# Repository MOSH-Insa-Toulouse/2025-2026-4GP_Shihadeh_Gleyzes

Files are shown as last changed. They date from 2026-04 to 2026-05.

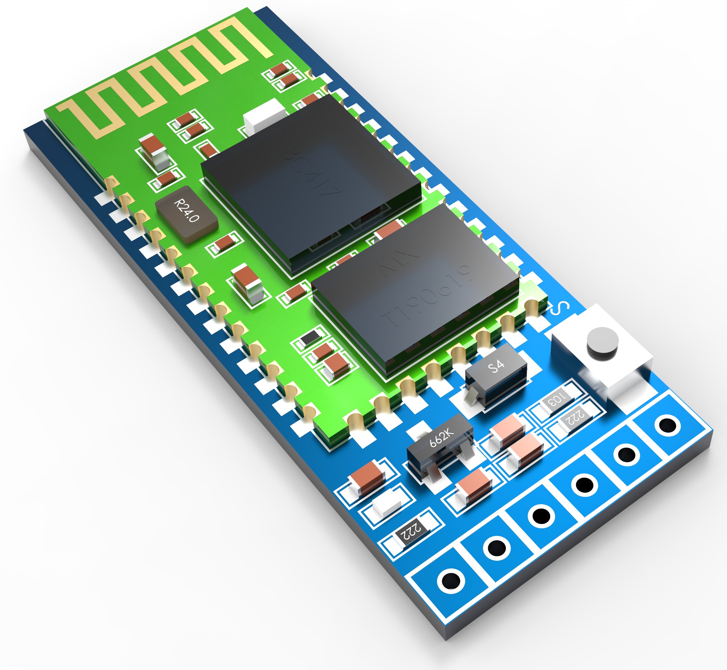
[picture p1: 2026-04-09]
Kicad/modules/module-bluetooth-hc05-1.snapshot.4/HC05_render.jpg

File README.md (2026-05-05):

#  Projet : Du capteur au banc de test - Jauge de contrainte en graphite

L'objectif principal de ce projet est d'évaluer une technologie "low-tech" : un capteur de déformation (jauge de contrainte) fabriqué à partir de graphite. Pour cela, nous avons conçu de A à Z une chaîne de mesure complète, allant de la physique du capteur jusqu'à l'application smartphone, en passant par le conditionnement électronique et la création d'un banc de test automatisé.

##  Équipe Projet
* **[Jules Gleyzes]**  **[Samy Shihadeh]**
* Année : 2025-2026

---

##  Sommaire des livrables
1. [Le Capteur en Graphite](#1-le-capteur-en-graphite-low-tech)
2. [Électronique Analogique et Simulation (LTspice)](#2-électronique-analogique-et-simulation-ltspice)
3. [Le Shield PCB (KiCad)](#3-le-shield-pcb-kicad)
4. [Le Code Arduino](#4-programmation-arduino)
5. [L'Application Android](#5-application-android)
6. [Le Banc de Test](#6-le-banc-de-test)
7. [La Datasheet Finale](#7-datasheet-du-capteur)
8. [Conclusion](#8-conclusion)

---

## 1. Le Capteur en Graphite (Low-Tech)
Notre jauge de contrainte a été fabriquée selon une approche "low-tech", en crayonnant simplement une zone spécifique sur une feuille de papier avec un crayon à papier (graphite). Derrière cette apparente simplicité se cache en réalité un capteur régi par la mécanique quantique. 
### 1.1. Géométrie et Fabrication 
**Support :** Papier classique.  **Matériau sensible :** Dépôt de graphite par frottement.  **Dimensions :** Motif en forme de "U" avec une longueur de bande de 35 mm et un espacement de 5 mm.



### 1.2. Principe Physique : 
Réseau de percolation et Effet Tunnel. Les traits de crayon déposés sur du papier forme un **réseau de percolation** : un grand nombre de micro et nano-grains de graphite dispersées de façon aléatoire. Pour que le courant traverse le capteur, les électrons utilisent deux mécanismes : 1. **La conduction ohmique :** Lorsque les grains se touchent physiquement. 2. **L'effet tunnel quantique :** Lorsque deux grains sont séparées par un vide ou un isolant nanométrique, les électrons (qui se comportent comme des ondes) ont une probabilité de "traverser" cette barrière. La résistance électrique liée à cet effet tunnel R_tunnel dépend de manière **exponentielle** de la distance d entre les grains de graphite.
### 1.3. Réponse à la déformation (Macroscopique) 
C'est cette sensibilité exponentielle à la distance nanométrique qui permet au capteur de mesurer une déformation mécanique. **En Tension (étirement / courbure vers l'extérieur) :** Les fibres du papier s'étirent, éloignant les grains de graphite les unes des autres. La distance d des jonctions augmente. L'effet tunnel ne fonctionne plus, ce qui **augmente fortement la résistance électrique globale**. **En Compression (courbure vers l'intérieur) :** Les fibres du papier se resserent. Les grains sont rapprochées, créant de nouveaux contacts physiques et diminuant la distance d des jonctions tunnel. Les électrons circulent beaucoup plus facilement, ce qui **diminue la résistance électrique**. Ce capteur low-tech est donc un détecteur quantique de variations de distances nanométriques.
## 2. Électronique Analogique et Simulation (LTspice)

Avant de passer à la réalisation physique sur notre shield, il est important de valider le comportement de notre signal de manière théorique. Nous avons utilisé le logiciel LTspice pour modéliser le circuit complet afin d'ajuster la valeur de nos composants et vérifier la réponse du système. Notre capteur en graphite possède une résistance électrique très élevée, il ne laisse donc passer qu'un courant de l'ordre du microampère. La carte Arduino ne lisant que des tensions (de 0 à 5V), une amplification du signal est donc essentiel.

### 2.1. Amplification Transimpédance et Étalonnage Dynamique

Le cœur de notre circuit repose sur un amplificateur opérationnel monté en transimpédance. Ce montage force le très faible courant du capteur à traverser la résistance de rétroaction R4 (100 kΩ) pour générer une tension de sortie que l’arduino est capable de lire. 

### 2.2. Filtrage des Parasites Ambiants

Le graphite et les fils de connexion apportent des signaux parasites à cause des ondes ambiantes. Pour obtenir une mesure propre et exploitable, nous avons étagé deux filtres. 

Le premier est un filtre actif formé par le condensateur C2 (1 µF) placé en parallèle de R4. Il crée un filtre passe-bas du premier ordre dont la fréquence de coupure est calculée par la formule f_c = 1/(2pi*R4*C2), ce qui donne environ 1.6 Hz. Cela bloque le bruit à 50 Hz tout en laissant passer les variations lentes correspondant à nos contraintes mécaniques. Enfin, un second filtre passe-bas, passif cette fois, est placé juste avant la broche de lecture de l'Arduino. Composé de R3 (1 kΩ) et C3 (100 nF), il possède une fréquence de coupure d'environ 1.6 kHz pour supprimer les bruits à très haute fréquence.

Schéma du circuit sur LTspice *LTspice*

## 3. Le Shield PCB (KiCad)
 Pour intégrer proprement notre circuit au microcontrôleur, nous avons conçu un "Shield" sur mesure à l'aide du logiciel **KiCad**. Le principe d'un shield est d'être une carte d'extension conçue pour se connecter directement par-dessus la carte Arduino UNO. Cette approche permet de supprimer le câblage pour avoir un tout plus compact et un visuel moins encombré. 
### Les Composants Intégrés 
Notre carte comprend un ensemble d’éléments matériels nécessaires au fonctionnement du système : 
* **Le capteur en graphite **
* **Le circuit d'amplification transimpédance :** Converti le micro-courant du capteur en une tension (0-5V) lisible par la carte arduino et de filtre les bruits parasites. 
* **Le potentiomètre :** Intégré au circuit d'amplification et piloté par la carte, il sert à étalonner le signal. Il adapte le gain en temps réel pour garantir une lecture précise, peu importe la résistance du capteur fabriqué.
* **L'écran OLED :** L'interface visuelle qui permet de lire les mesures en direct et de visualiser les différents menus de la carte. 
* **L'encodeur rotatif :** Molette cliquable permettant à l'utilisateur de naviguer dans les menus de l'écran et de déclencher les mesures. 
* **Le module Bluetooth :** Transmet les données traitées en temps réel vers notre application smartphone Android. 



### De la Conception à la Réalisation 
Pour aboutir à notre carte physique, nous sommes passés par deux grandes étapes de conception sur KiCad : 
**1. Le Schématique Électrique** C'est ici que nous avons défini les liens logiques entre tous nos composants et le microcontrôleur, en utilisant des labels pour garder un document lisible.

Schematique

**2. Le Routage (PCB)** Une fois le schéma validé, nous avons placé physiquement les composants sur une carte et tracé les pistes de cuivre (en respectant une largeur et une isolation de 0.5 mm minimum).

PCB

## 4. Programmation Arduino

Tous les composants de notre shield sont pilotés par une carte Arduino UNO. Le code est disponible dans ce dépôt.

Dès qu'on branche la carte, l'Arduino lance une **calibration automatique**. Le programme va tester rapidement plusieurs valeurs sur le potentiomètre numérique pour s'adapter tout seul à la résistance de votre capteur.

Ensuite, l'écran OLED affiche le menu principal. La navigation se fait très simplement avec l'encodeur rotatif : il suffit de tourner la molette pour faire défiler les menus, et de cliquer dessus pour y entrer.

Le programme propose deux menus :

* **Menu 1 : Mesure en direct** Affiche la résistance du capteur graphite en temps réel. Le code adapte tout seul l'unité (Ohms, kOhms ou MOhms). Pour que l'affichage soit agréable à lire et que les chiffres ne sautent pas dans tous les sens, nous avons ajouté un petit filtre dans le code qui fait une moyenne sur les 15 dernières mesures.

* **Menu 2 : Infos Créateurs**
Un petit menu de crédits qui affiche les informations de notre binôme (Samy Shihadeh & Jules Gleyzes - GP 4A 2026).

## 5. Application Android 

Pour visualiser les données de notre capteur sans avoir besoin d'un ordinateur, nous avons développé une petite application Android. Elle communique directement avec le module Bluetooth de notre carte.

Nous avons créé cette application en utilisant MIT App Inventor qui permet grâce à un système de programmation par blocs de développer rapidement une application fonctionnelle.

L'application a deux rôles principaux :
1. **La connexion :** Elle permet de chercher et de se connecter facilement au module Bluetooth.
3. **L'affichage :** Une fois connectée, elle reçoit les valeurs de résistance mesurées et les affiche sur l'écran du téléphone quand on appuie dessus.

**L'interface utilisateur :**

Appli

**Le code par blocs :**

Scratch appli

## 6. Le Banc de Test

Pour valider scientifiquement l'efficacité de nos capteurs "low-tech" en graphite, il était indispensable de caractériser leur réponse face à des déformations mécaniques connues. 

Nous avons conçu un banc de test en utilisant une pièce imprimée en 3D en forme de cône. Celui-ci possède différents rayons de courbure de sorte que l’on puisse tordre nos différent de capteurs, fait à partir de différents types de graphite, de la même manière.



Afin d'évaluer et de comparer les performances de nos différents capteurs, nous avons étudié l'évolution de leur signal en fonction de la contrainte mécanique appliquée. Pour ce faire, nous avons tracé la variation relative de la résistance (R - R_0)/R_0 en fonction de la déformation. Avec R la résistance du capteur sous contrainte et R_0 la résistance du capteur lorsqu'il est à plat.

## 7. Datasheet du Capteur

Pour valider le fonctionnement du capteur, nous avons mesuré l'évolution de sa résistance relative (ΔR/R_0) en fonction de la déformation appliquée, en testant différentes duretés de mines de graphite. 





Bien que ces courbes valident le principe physique de base (la résistance augmente en extension et diminue en compression grâce à l'effet tunnel), elles mettent également en évidence les limites du capteur *low-tech* fabriqué à la main :

* **Non-linéarité et variabilité :** L'épaisseur du dépôt de graphite n'étant pas parfaitement uniforme lors d'un coloriage manuel, la réponse électrique présente des irrégularités selon les échantillons.
* **La limite de rupture mécanique :** Sur le graphique de compression, on observe une remontée anormale et soudaine de la résistance pour des déformations supérieures à 0,004. Cela peut s'expliquer par la nature du substrat : au-delà d'un certain angle, le papier ne fait plus que se courber, il peut se casser en marquant un pli. Cette pliure casse physiquement les chemins de percolation du graphite, faussant totalement la mesure.

## 8. Conclusion

Ce projet nous a permis de prouver qu'il est possible de créer un capteur de flexion fonctionnel avec un simple crayon à papier. 

Le comportement du capteur dépend directement de la composition de la mine, qui est un mélange de **graphite** (conducteur) et **d'argile** (isolant) :

* **Les mines grasses (ex: 3B) :** Riches en graphite, elles déposent une couche épaisse et très conductrice sur le papier.Le capteur est donc **stable et linéaire, mais moins sensible**.
* **Les mines dures (ex: 3H) :** Riches en argile (isolante) et pauvres en graphite, elles laissent un dépôt plus fin. À la moindre déformation, ce fragile réseau conducteur risque de se rompre partiellement. Le capteur devient alors **extrêmement sensible**, mais ses mesures sont plus difficiles à répéter.
On a pu voir que plus la mine du crayon est dure, plus le capteur réagit fort. Cependant, les mines classiques (HB, 2B) offrent des mesures plus stables.

### Peut-on industrialiser ce capteur ?
À grande échelle, **non**. Le principal problème est qu'il est impossible de colorier deux capteurs exactement de la même manière à la main. Les résultats sont donc trop variables pour l'industrie. De plus, les tests réalisés sur les capteur ont démontré leurs manque de duraibilité, les morceaux de papier se cassent après peu d'utilisations.

Précision après présentation :

La qualité de nos mesure ne permet pas de s'exprimer clairement sur la possibilité d'industrialiser ce capteur, cependant notre capteur a très basse compression ou extension démontre une sensibilité extremement bonne (par exemple nous avons presque une sensibilité de 100 pour le crayon B en compression) ce qui nous laisse a penser qu'après stabilisation des mesures avec des modifications apportées sur nos capteurs, ils pourraient avoir des caractéristiques interessantes d'un point de vu performance.

Une piste possible serait d'appliquer de la lacque ou encore de chauffer nos capteur avant test pour bien fixer le graphite sur notre feuille et refaire nos mesures pour déterminer si nos capteurs se comportent normalement.

De plus, son coût quasi nul et sa simplicité de fabrication en font un très bon outil éducatif qui permettent de découvrir tout les aspects nécessaire à prendre en compte et à étudier dans la création d'un capteur.

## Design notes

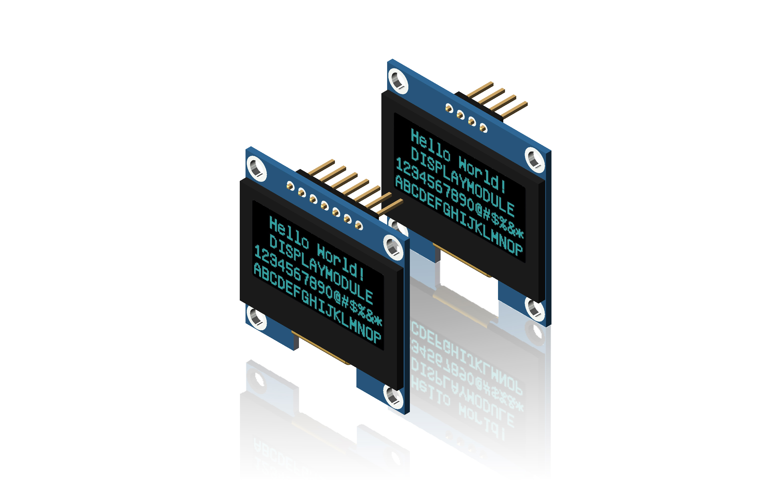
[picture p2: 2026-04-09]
Kicad/modules/1-3-oled-display-128x64-1.snapshot.5/1.inch OLED Display Overview.jpg

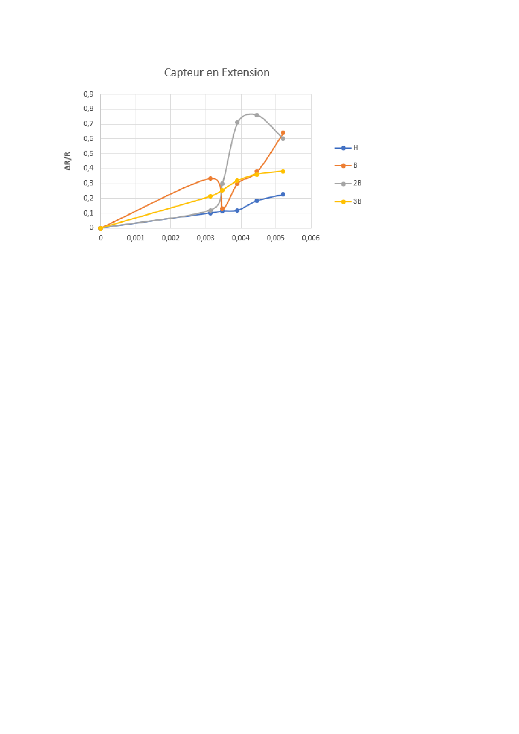
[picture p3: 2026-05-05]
Kicad/Photo pour Github/courbe-extension.png

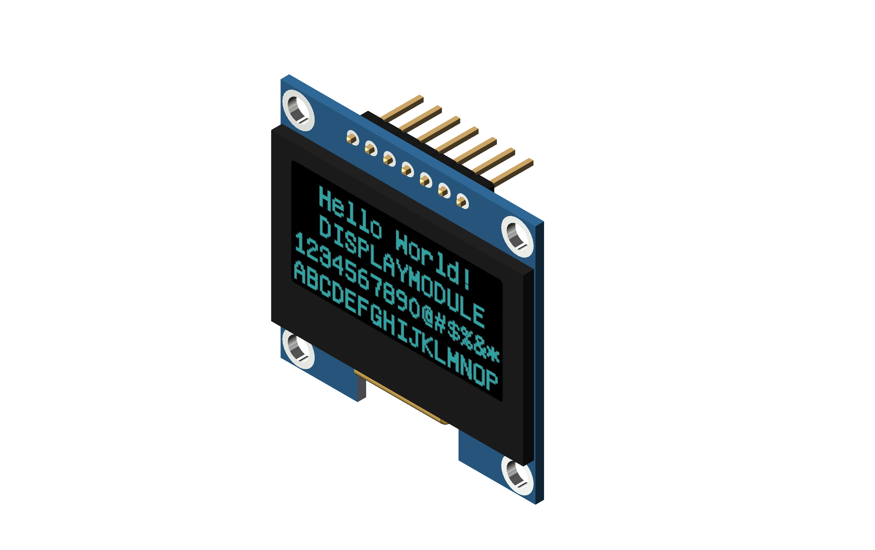
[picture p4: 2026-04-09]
Kicad/modules/1-3-oled-display-128x64-1.snapshot.5/DM-OLED13-625.jpg

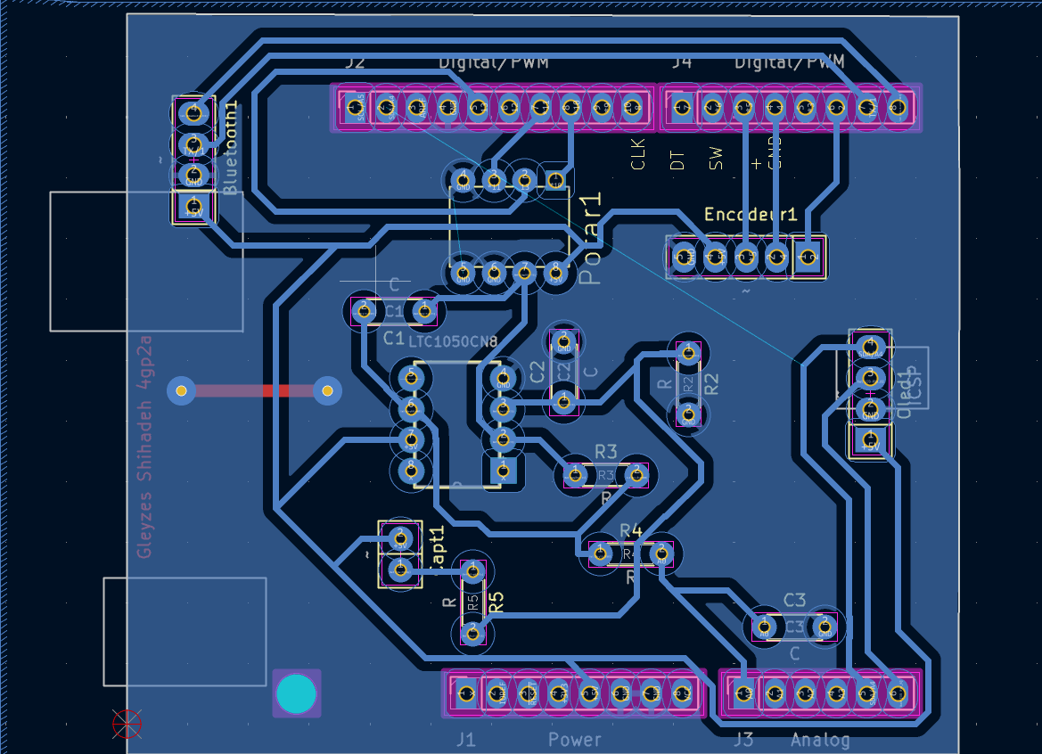
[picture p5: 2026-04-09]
Kicad/Photo pour Github/PCB.png

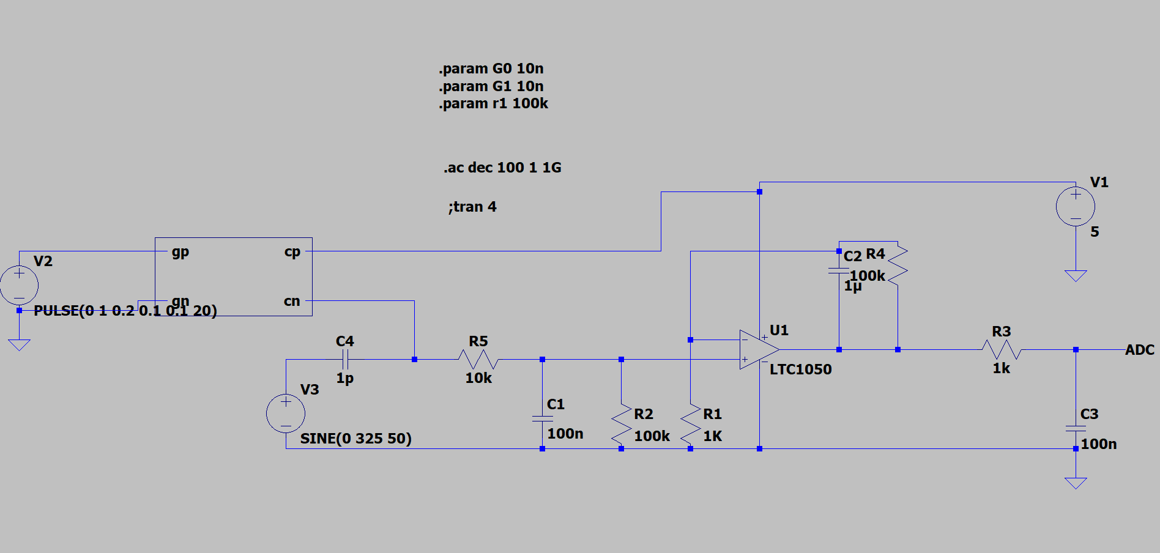
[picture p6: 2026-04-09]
Kicad/Photo pour Github/LTspice.png

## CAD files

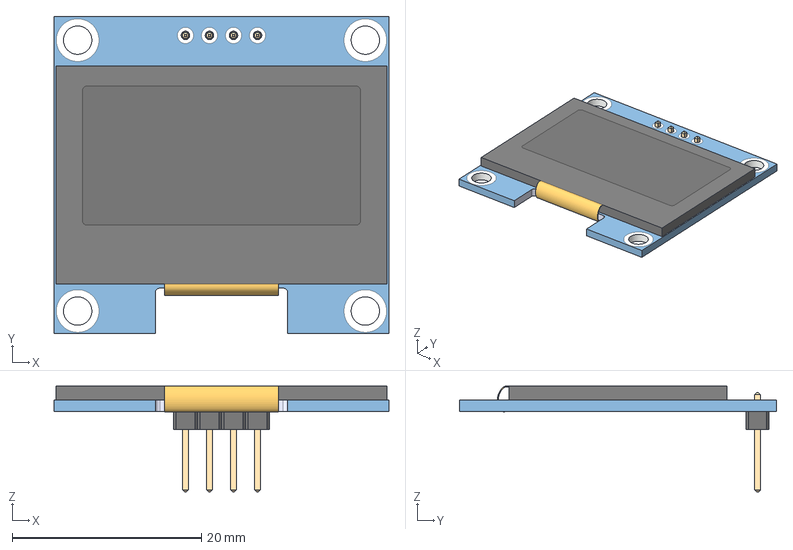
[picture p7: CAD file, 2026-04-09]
Kicad/modules/1-3-oled-display-128x64-1.snapshot.5/stp/AZ-Delivery - OLED13 IIC.stp
35.4 x 33.5 x 11.2 mm

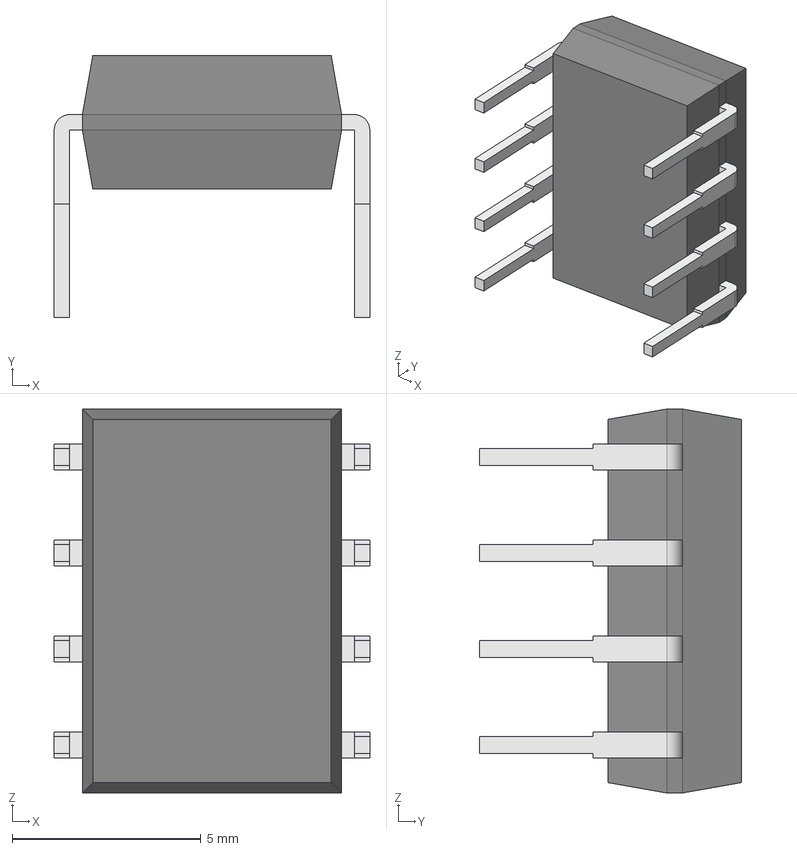
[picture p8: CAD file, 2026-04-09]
Kicad/modules/LTC1050CN8/LTC1050CN8.step
8.35 x 6.93 x 10.2 mm
Body001 (Mirror #1) x 5

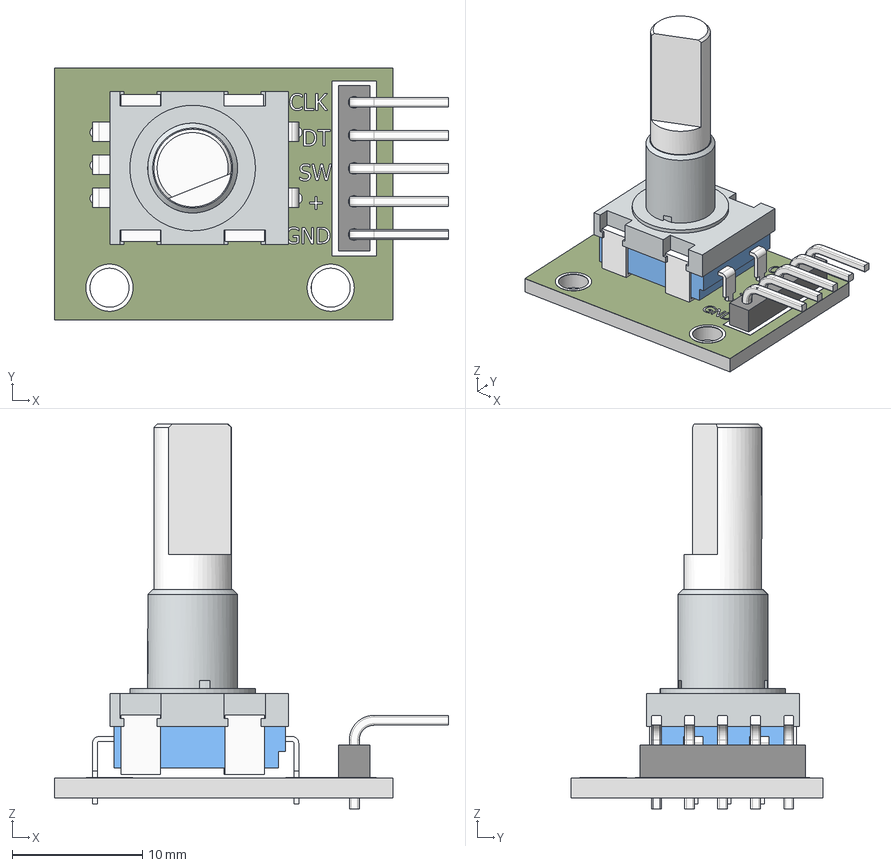
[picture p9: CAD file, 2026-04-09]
Kicad/modules/rotary-encoders-1.snapshot.1/rotary+encoder_17mm_hole_spc.stp
30.3 x 19.3 x 29.6 mm
pcb
mtg flange
body_encoder
5 pin header
90d pin_header x 5
decal_encoder
pins_encoder body_2 x 5
shaft_encoder

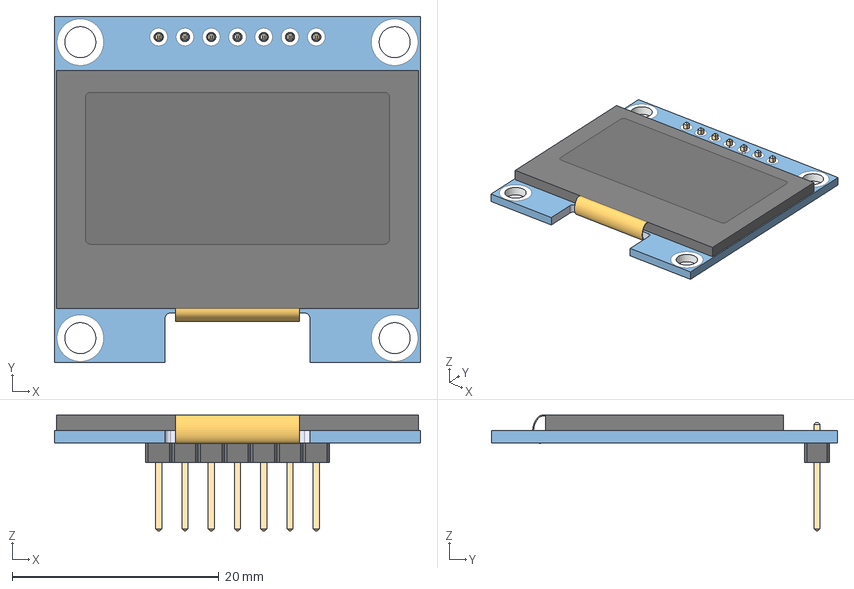
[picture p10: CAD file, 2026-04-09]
Kicad/modules/1-3-oled-display-128x64-1.snapshot.5/stp/HiLetgo - DM-OLED13-625.stp
35.4 x 33.5 x 11.2 mm

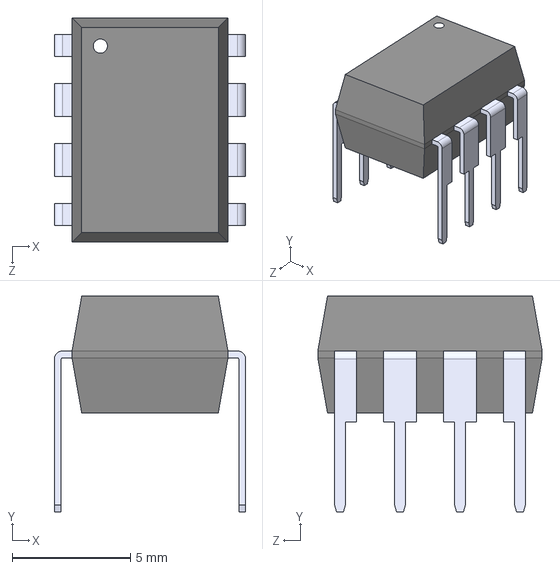
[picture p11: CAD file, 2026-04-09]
Kicad/modules/MCP41010-E_P/MCP41010-E_P.step
8.10 x 9.14 x 9.50 mm

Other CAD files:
Kicad/modules/rotary-encoders-1.snapshot.1/rotary+encoder_14mm_hole_spc.stp

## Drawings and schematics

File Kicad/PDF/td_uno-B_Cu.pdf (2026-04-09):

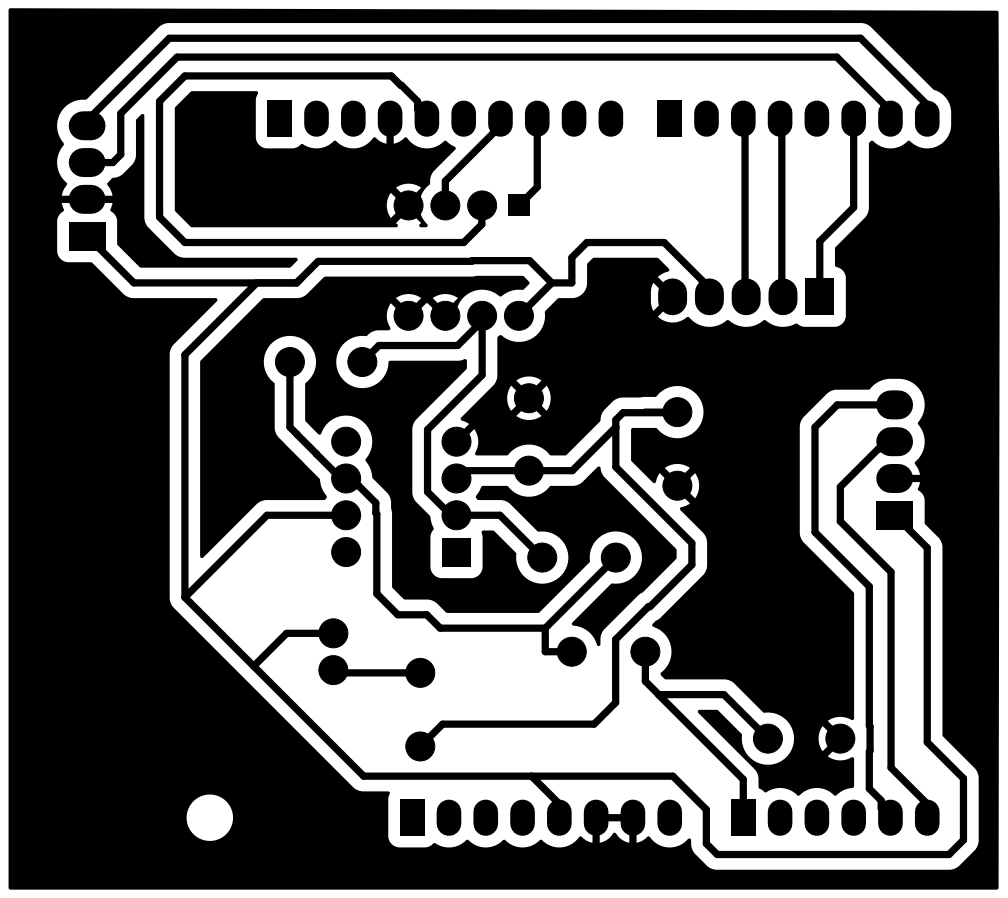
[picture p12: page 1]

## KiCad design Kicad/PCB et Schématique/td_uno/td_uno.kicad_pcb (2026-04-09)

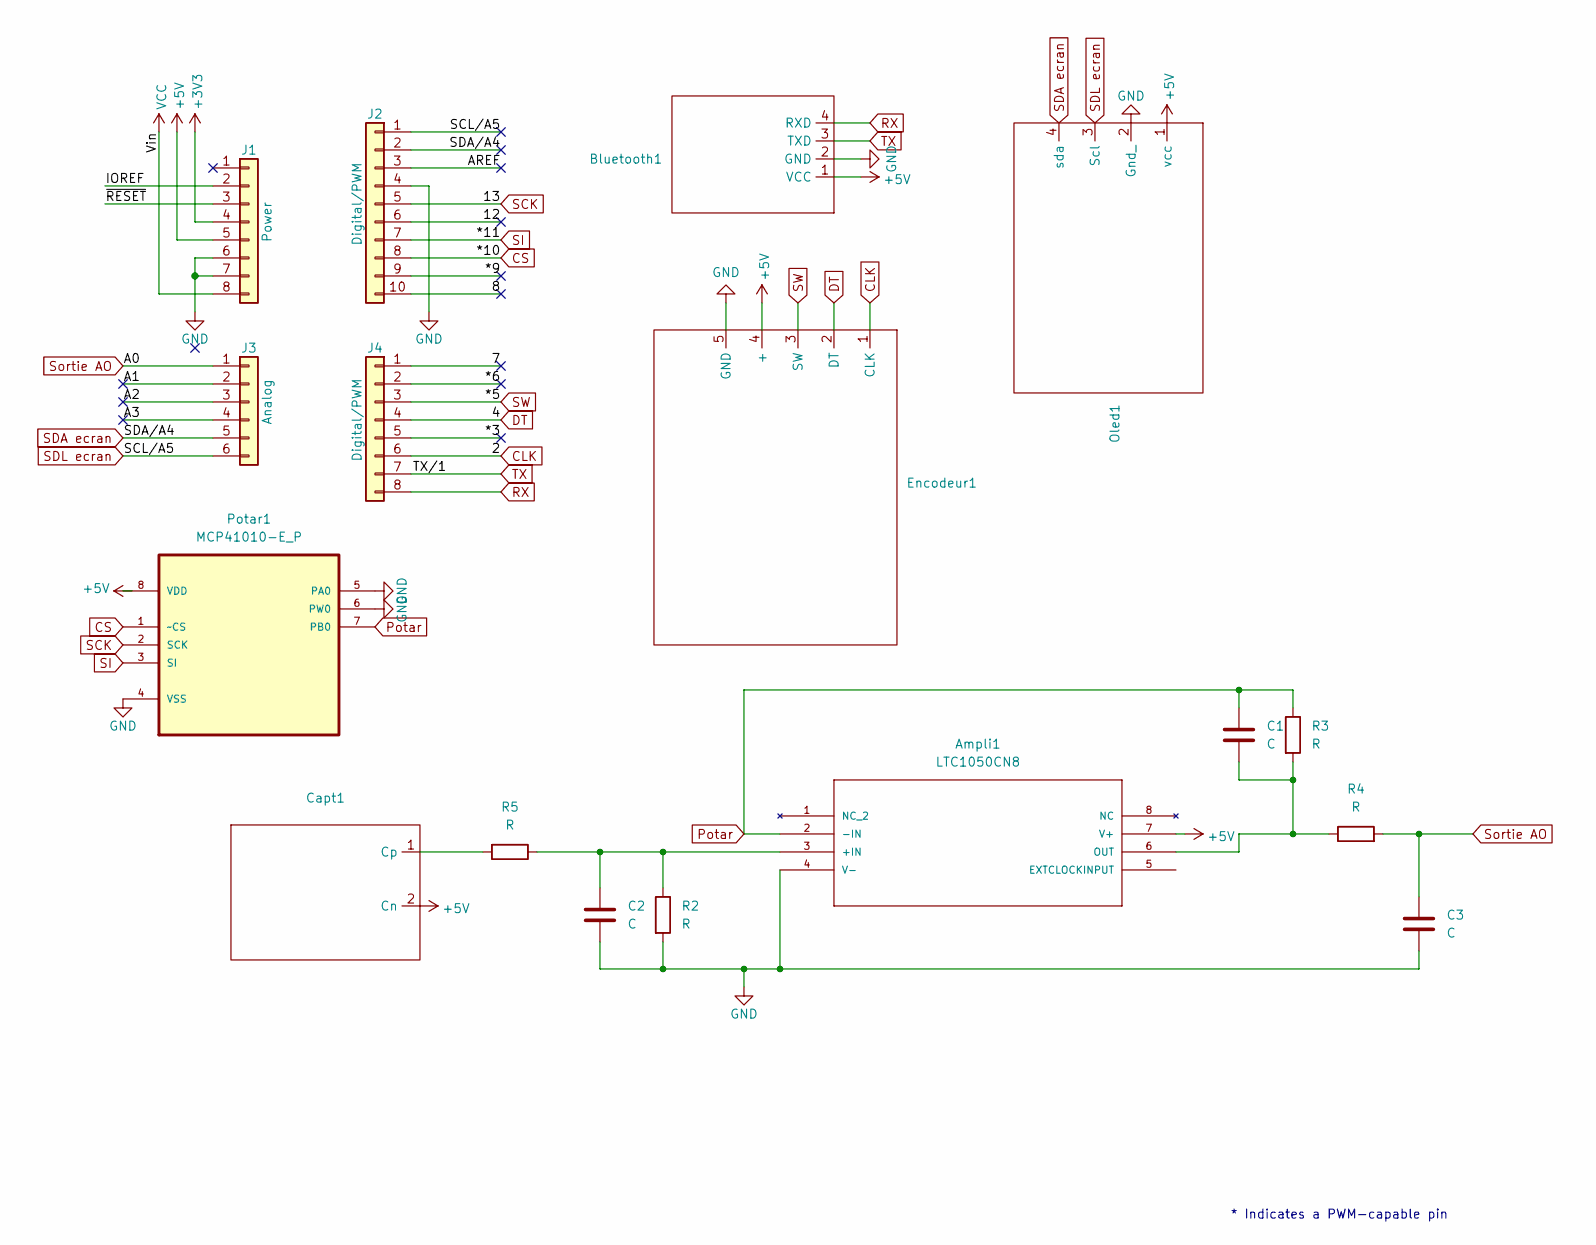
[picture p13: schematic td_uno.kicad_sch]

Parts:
Ampli1: LTC1050CN8; Ampli; MANUFACTURER_PART_NUMBER ltc1050cn8
Bluetooth1: Bluetooth
C1, C2, C3: C; C_Disc_D4.3mm_W1.9mm_P5.00mm
Capt1: Capt
Encodeur1: Encodeur
J1: Power; PinSocket_1x08_P2.54mm_Vertical
J2: Digital/PWM; PinSocket_1x10_P2.54mm_Vertical
J3: Analog; PinSocket_1x06_P2.54mm_Vertical
J4: Digital/PWM; PinSocket_1x08_P2.54mm_Vertical
Oled1: Oled
Potar1: MCP41010-E_P; Potar; MPN MCP41010-E/P; DigiKey_Part_Number MCP41010-E/P-ND
R2, R3, R4, R5: R; R_Axial_DIN0204_L3.6mm_D1.6mm_P5.08mm_Horizontal

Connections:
+3V3: J1.4
+5V: Ampli1.7 (V+), Bluetooth1.1 (VCC), Capt1.2 (Cn), Encodeur1.4 (+), J1.5, Oled1.1 (vcc), Potar1.8 (VDD)
/7: J4.1
/8: J2.10
/12: J2.6
/*3: J4.5
/*6: J4.2
/*9: J2.9
/A1: J3.2
/A2: J3.3
/A3: J3.4
/AREF: J2.3
/IOREF: J1.2
/~RESET: J1.3
CLK: Encodeur1.1 (CLK), J4.6
CS: J2.8, Potar1.1 (~CS)
DT: Encodeur1.2 (DT), J4.4
GND: Ampli1.4 (V-), Bluetooth1.2 (GND), C2.2, C3.2, Encodeur1.5 (GND), J1.6, J1.7, J2.4, Oled1.2 (Gnd_), Potar1.4 (VSS), Potar1.5 (PA0), Potar1.6 (PW0), R2.2
unnamed: Ampli1.3 (+IN), C2.1, R2.1, R5.1
unnamed: Ampli1.6 (OUT), C1.2, R3.2, R4.1
unnamed: Capt1.1 (Cp), R5.2
Potar: Ampli1.2 (-IN), C1.1, Potar1.7 (PB0), R3.1
RX: Bluetooth1.4 (RXD), J4.8
SCK: J2.5, Potar1.2 (SCK)
SDA ecran: J2.2, J3.5, Oled1.4 (sda)
SDL ecran: J2.1, J3.6, Oled1.3 (Scl)
SI: J2.7, Potar1.3 (SI)
SW: Encodeur1.3 (SW), J4.3
Sortie AO: C3.1, J3.1, R4.2
TX: Bluetooth1.3 (TXD), J4.7
VCC: J1.8

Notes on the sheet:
* Indicates a PWM-capable pin

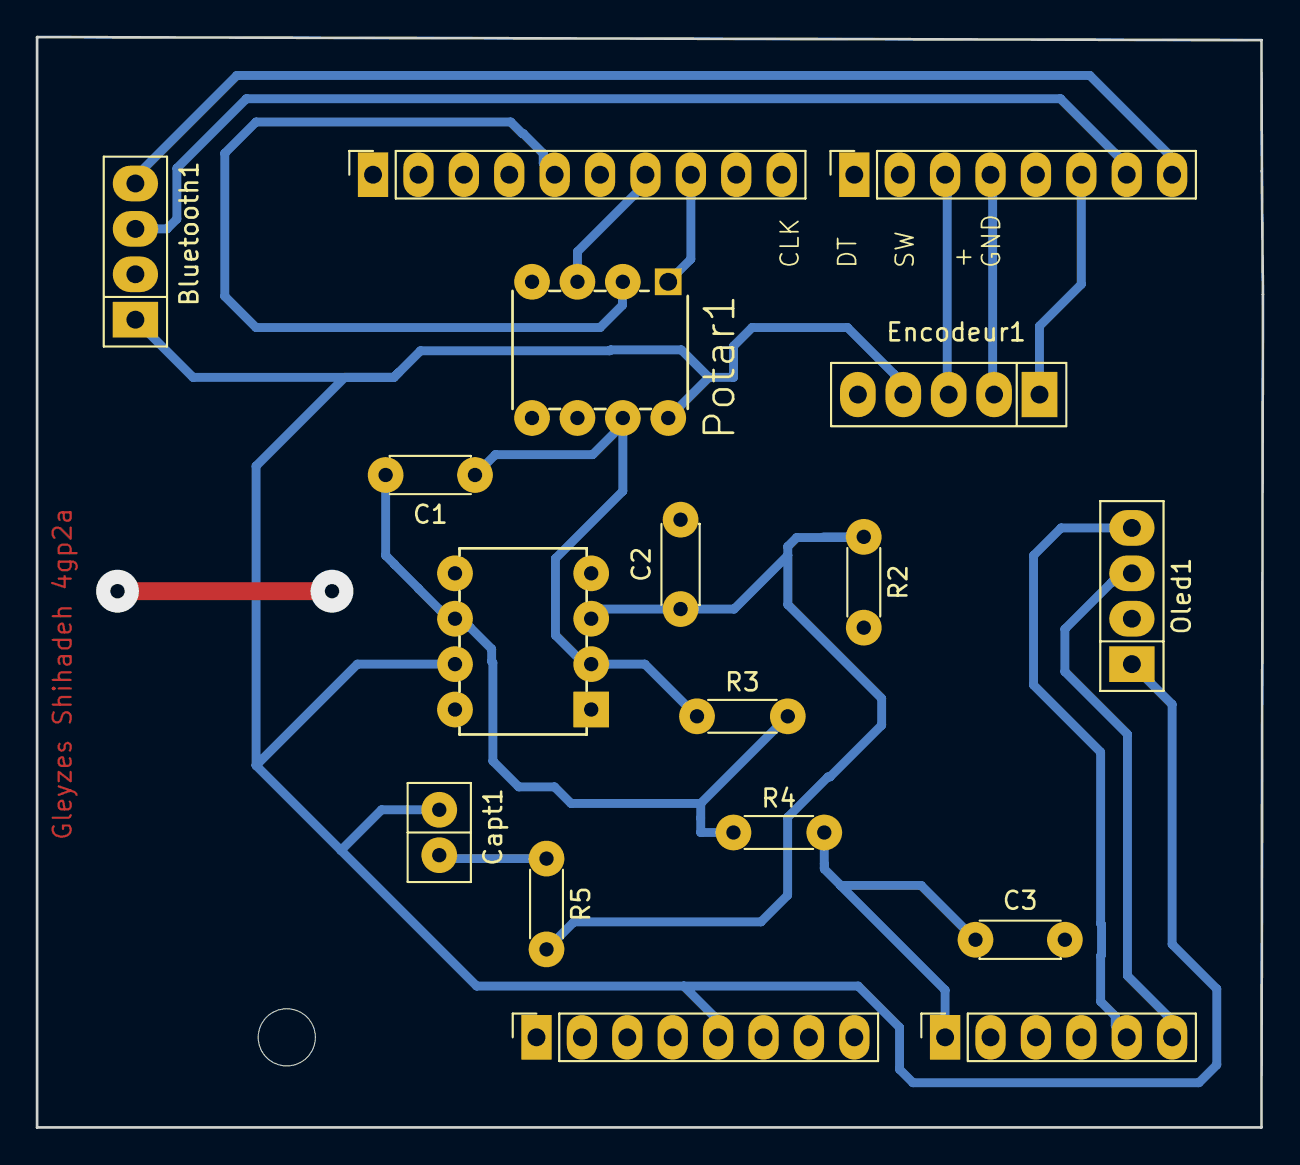
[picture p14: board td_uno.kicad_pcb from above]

Board: 2 copper layers, 68.6 x 61.0 mm, 18 parts (0 on the bottom side), 17 nets.

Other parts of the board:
MH2: MountingHole_3.2mm

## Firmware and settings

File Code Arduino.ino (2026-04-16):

#include <Wire.h>            
#include <Adafruit_GFX.h>     
#include <Adafruit_SSD1306.h> 
#include <SPI.h>            

// =============================================================================
//                                CONFIGURATION PINS
// =============================================================================

// --- Encodeur Rotatoire ---
#define ENCODER_CLK_PIN 2
#define ENCODER_DT_PIN 4
#define ENCODER_SW_PIN 5

// --- Ecran OLED SSD1306 ---
#define OLED_WIDTH 128
#define OLED_HEIGHT 64
#define OLED_RESET -1
#define OLED_ADDR 0x3C

// --- Capteur & Potar ---
#define GRAPHITE_SENSOR_PIN A0 
#define POT_CS_PIN 10      

// =============================================================================
//                            CONSTANTES & VARIABLES
// =============================================================================

// --- Mesure stable ---
const int ValMeasure = 15;   
int Measure[ValMeasure];    
int readIndex = 0;            
long total = 0;               

// --- Carac Circuit ---
const float VCC = 5.0;
const float R2 = 100000.0;
const float R4 = 100000.0;
const float R3 = 10000.0;

// --- Potar ---
const int POT_MAX_POS = 255;   
const long POT_BASE_RESISTANCE = 50000;  
const byte POT_OFFSET = 10000;
const byte POT_ADDR_0 = 0x11; 
int potPosition = 128;        
float potResValue = 17000.0;  

// --- Ecran  ---
Adafruit_SSD1306 display(OLED_WIDTH, OLED_HEIGHT, &Wire, OLED_RESET);

volatile int encoderPos = 0; 
int lastEncoderPos = 0;       
int menuSelection = 0;        
bool inSubMenu = false;       
unsigned long lastUpdate = 0;



// =============================================================================
//                                   FONCTIONS 
// =============================================================================


// Detection sens encodeur & interrupt
 
void onEncoderInterrupt() {
  if (digitalRead(ENCODER_CLK_PIN) == HIGH) {
    if (digitalRead(ENCODER_DT_PIN) == HIGH) encoderPos++;
    else encoderPos--;
  }
}


//MAJ potar via SPI

void updateDigitalPot(int position) {
  position = constrain(position, 0, 255);
  digitalWrite(POT_CS_PIN, LOW);
  SPI.transfer(POT_ADDR_0);
  SPI.transfer(position);
  digitalWrite(POT_CS_PIN, HIGH);
  
  // Calcul de la résistance réelle équivalente
  potResValue = (POT_BASE_RESISTANCE * position / POT_MAX_POS) + POT_OFFSET;
}


 // Mesure stable

int stableMeasure() {
  total = total - Measure[readIndex];
  Measure[readIndex] = analogRead(GRAPHITE_SENSOR_PIN);
  total = total + Measure[readIndex];
  readIndex = (readIndex + 1) % ValMeasure; // Incrémente et boucle
  return total / ValMeasure;
}

//Calcule Graph Volt
float getGraphiteVoltage(){
  int adcValue = analogRead(GRAPHITE_SENSOR_PIN);
  return adcValue * VCC / 1023.0;
}
//Calcule Graph Res
float getGraphiteRes() {
  int adc = stableMeasure();
  float Vadc = adc * VCC / 1023.0;

  if (Vadc < 0.05) return -1.0; // Seuil 
  
  return R2 * (1.0 + R4 / potResValue) * (VCC / Vadc) - R2 - R3;
}

// Routine de démarrage : Cherche une plage de mesure optimale

void calibration() {
  display.clearDisplay();
  display.setTextSize(1);
  display.setTextColor(SSD1306_WHITE);
  display.setCursor(15, 25);
  display.println(F("CALIBRATION..."));
  display.display();

const float targetVoltage = 2.5;
  int bestPos = 0;
  float minDiff = 5.0; 
  for (int pos = 0; pos <= 255; pos += 5) {
    updateDigitalPot(pos);
    delay(40); 
    
    float v = getGraphiteVoltage();
    float diff = abs(v - targetVoltage);
    if (diff < minDiff) {
      minDiff = diff;
      bestPos = pos;
    }
  }
  
  // On applique la meilleure position trouvée
  potPosition = bestPos;
  updateDigitalPot(potPosition);
}
// =============================================================================
//                                  SETUP
// =============================================================================

void setup() {
  Serial.begin(9600);

  // Config Inputs
  pinMode(ENCODER_CLK_PIN, INPUT_PULLUP);
  pinMode(ENCODER_DT_PIN, INPUT_PULLUP);
  pinMode(ENCODER_SW_PIN, INPUT_PULLUP);
  attachInterrupt(digitalPinToInterrupt(ENCODER_CLK_PIN), onEncoderInterrupt, RISING);

  // Config Outputs
  pinMode(POT_CS_PIN, OUTPUT);
  digitalWrite(POT_CS_PIN, HIGH);
  SPI.begin();

  // Init Ecran
  if(!display.begin(SSD1306_SWITCHCAPVCC, OLED_ADDR)) {
    for(;;); // Bloque si écran non trouvé
  }

  // Init Lissage
  for (int i = 0; i < ValMeasure; i++) Measure[i] = 0;

  calibration();
  display.clearDisplay();
}

// =============================================================================
//                                  BOUCLE PRINCIPALE
// =============================================================================

void loop() {
  
  // 1. GESTION DU BOUTON (Navigation Menu/Sous-menu)
  if (digitalRead(ENCODER_SW_PIN) == LOW) {
    delay(50);
    inSubMenu = !inSubMenu;
    display.clearDisplay(); // Nettoyage lors du changement de page
    while (digitalRead(ENCODER_SW_PIN) == LOW); // Attente relâchement
  }

  // 2. GESTION DE L'ENCODEUR
  if (!inSubMenu) {
    menuSelection = abs(encoderPos / 2) % 2; 
  } 
  else if (menuSelection == 0) { // On est dans le menu Mesure
    if (encoderPos != lastEncoderPos) {
      potPosition = constrain(potPosition + (encoderPos - lastEncoderPos), 0, 255);
      updateDigitalPot(potPosition);
      lastEncoderPos = encoderPos;
    }
  }

  // 3. AFFICHAGE (Frequence : ~6Hz)
  if (millis() - lastUpdate > 150) {
    lastUpdate = millis();
    display.clearDisplay();
    display.setTextColor(SSD1306_WHITE);

    if (!inSubMenu) {
      // --- ÉCRAN D'ACCUEIL ---
      display.setTextSize(1);
      display.setCursor(25, 0); display.println(F("PROJET GRAPH'"));
      display.drawLine(0, 10, 128, 10, SSD1306_WHITE);
      
      display.setCursor(0, 25);
      display.print(menuSelection == 0 ? F("> MESURE ") : F("  CAPTEUR"));
      display.setCursor(0, 45);
      display.print(menuSelection == 1 ? F("> CREDITS") : F("  BINOME"));
    } 
    else {
      // --- SOUS-MENUS ---
      if (menuSelection == 0) { // Page Mesure
        float rGraph = getGraphiteRes();
        
        display.setTextSize(1);
        display.setCursor(0, 0); display.println(F("MESURE EN DIRECT"));
        display.print(F("Gain (Pot): ")); display.print(potResValue, 0); display.println(F(" Ohm"));
        
        display.setCursor(0, 30);
        if (rGraph < 0) {
          display.setTextSize(2); display.print(F("CONNECTER"));
        } else {
          display.setTextSize(2);
          if (rGraph > 1000000.0) { display.print(rGraph/1000000.0, 1); display.print(F(" M")); }
          else if (rGraph > 1000.0) { display.print(rGraph/1000.0, 1); display.print(F(" k")); }
          else { display.print(rGraph, 0); }
          display.setTextSize(1); display.print(F(" Ohm"));
        }
        
        Serial.println(rGraph); 
      } 
      else { // Page Crédits
        display.setTextSize(1);
        display.setCursor(0, 0); display.println(F("EQUIPE PROJET"));
        display.drawLine(0, 12, 128, 12, SSD1306_WHITE);
        display.setCursor(0, 25); display.println(F("Samy Shihadeh"));
        display.setCursor(0, 40); display.println(F("Jules Gleyzes"));
        display.setCursor(0, 55); display.println(F("GP 4A - 2026"));
      }
    }
    display.display(); 
  }
}

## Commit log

2026-04-09 Enhance README with sensor operation details
    Added detailed explanation of the percolation network and tunneling effect in the sensor's operation, including its response to mechanical deformation.
2026-04-13 Add Arduino code section to README
    Added Arduino code section with functionality details and menu descriptions.
2026-04-13 Fix link text for Arduino code section in README
2026-04-14 Update Code Arduino.ino
2026-04-15 Expand sensor datasheet with performance analysis
    Added detailed analysis of sensor performance and limitations based on resistance measurements. Discussed the impact of graphite hardness on sensor sensitivity and durability.

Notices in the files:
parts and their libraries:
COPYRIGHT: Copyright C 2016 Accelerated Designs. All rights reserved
